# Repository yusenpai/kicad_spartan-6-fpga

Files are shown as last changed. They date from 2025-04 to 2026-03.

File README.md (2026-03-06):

# Spartan 6 FPGA Dev Board

Đây là thiết kế của một board FPGA dựa trên Xilinx Spartan-6 XC6SLX16, kiểu chân BGA 324 chân. Board tương thích với slot mini PCI Express. Trên board tích hợp 256MB DRAM DDR3, 1Gb NAND Flash và 32Mb NOR Flash phục vụ cho mục đích lưu trữ file cấu hình FPGA.
Board này phục vụ cho mục đích học tập, nghiên cứu liên quan tới FPGA.

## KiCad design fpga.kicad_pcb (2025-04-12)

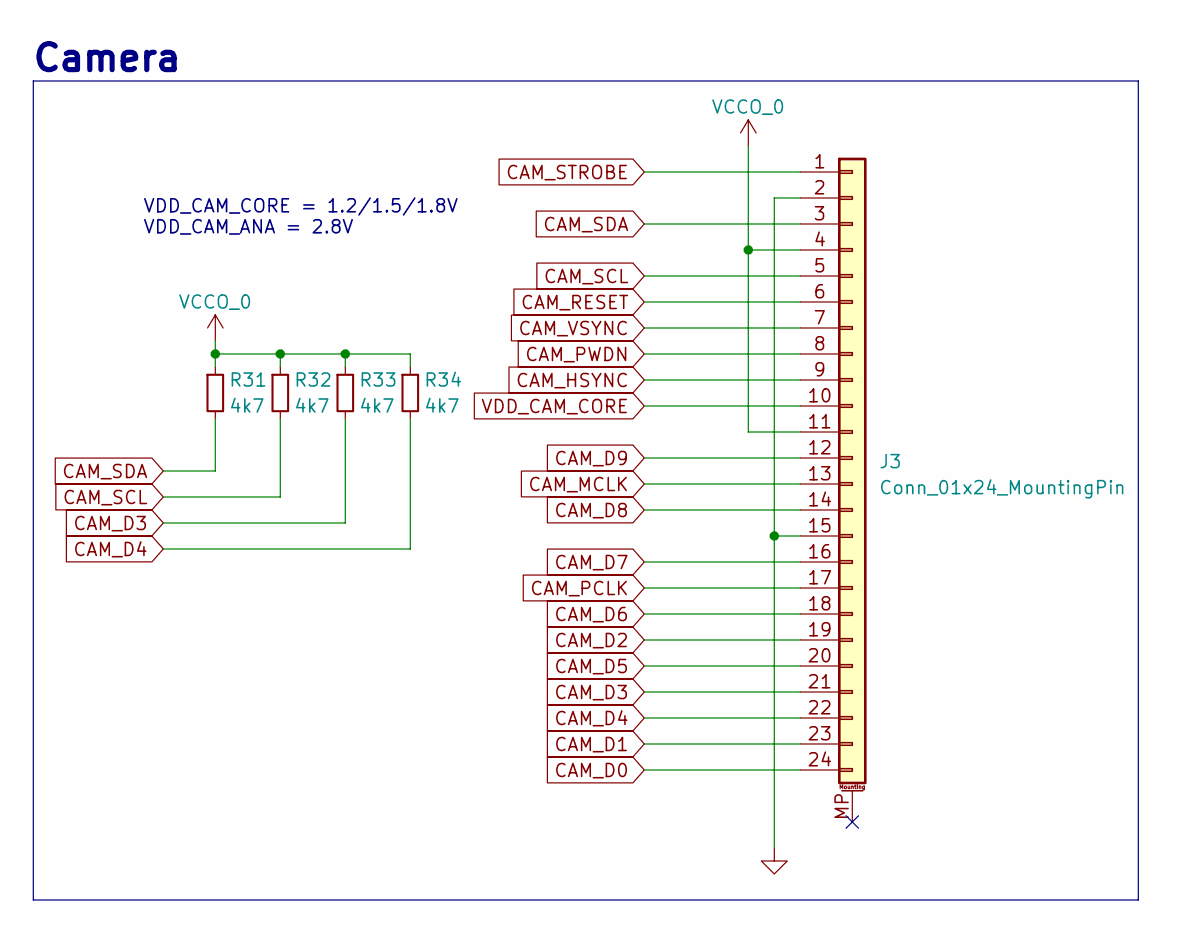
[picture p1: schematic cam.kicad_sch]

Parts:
J3: Conn_01x24_MountingPin; FPC-24P0.5
R31, R32, R33, R34: 4k7; R_0402_1005Metric

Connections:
+3V3: J3.4, J3.11, R31.1, R32.1, R33.1, R34.1; also elsewhere on the board
CAM_D0: J3.24; also elsewhere on the board
CAM_D1: J3.23; also elsewhere on the board
CAM_D2: J3.19; also elsewhere on the board
CAM_D3: J3.21, R33.2; also elsewhere on the board
CAM_D4: J3.22, R34.2; also elsewhere on the board
CAM_D5: J3.20; also elsewhere on the board
CAM_D6: J3.18; also elsewhere on the board
CAM_D7: J3.16; also elsewhere on the board
CAM_D8: J3.14; also elsewhere on the board
CAM_D9: J3.12; also elsewhere on the board
CAM_HSYNC: J3.9; also elsewhere on the board
CAM_MCLK: J3.13; also elsewhere on the board
CAM_PCLK: J3.17; also elsewhere on the board
CAM_PWDN: J3.8; also elsewhere on the board
CAM_RESET: J3.6; also elsewhere on the board
CAM_SCL: J3.5, R32.2; also elsewhere on the board
CAM_SDA: J3.3, R31.2; also elsewhere on the board
CAM_STROBE: J3.1; also elsewhere on the board
CAM_VSYNC: J3.7; also elsewhere on the board
GND: J3.2, J3.15; also elsewhere on the board
VDD_CAM_CORE: J3.10; also elsewhere on the board

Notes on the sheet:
Camera
VDD_CAM_CORE = 1.2/1.5/1.8V VDD_CAM_ANA = 2.8V

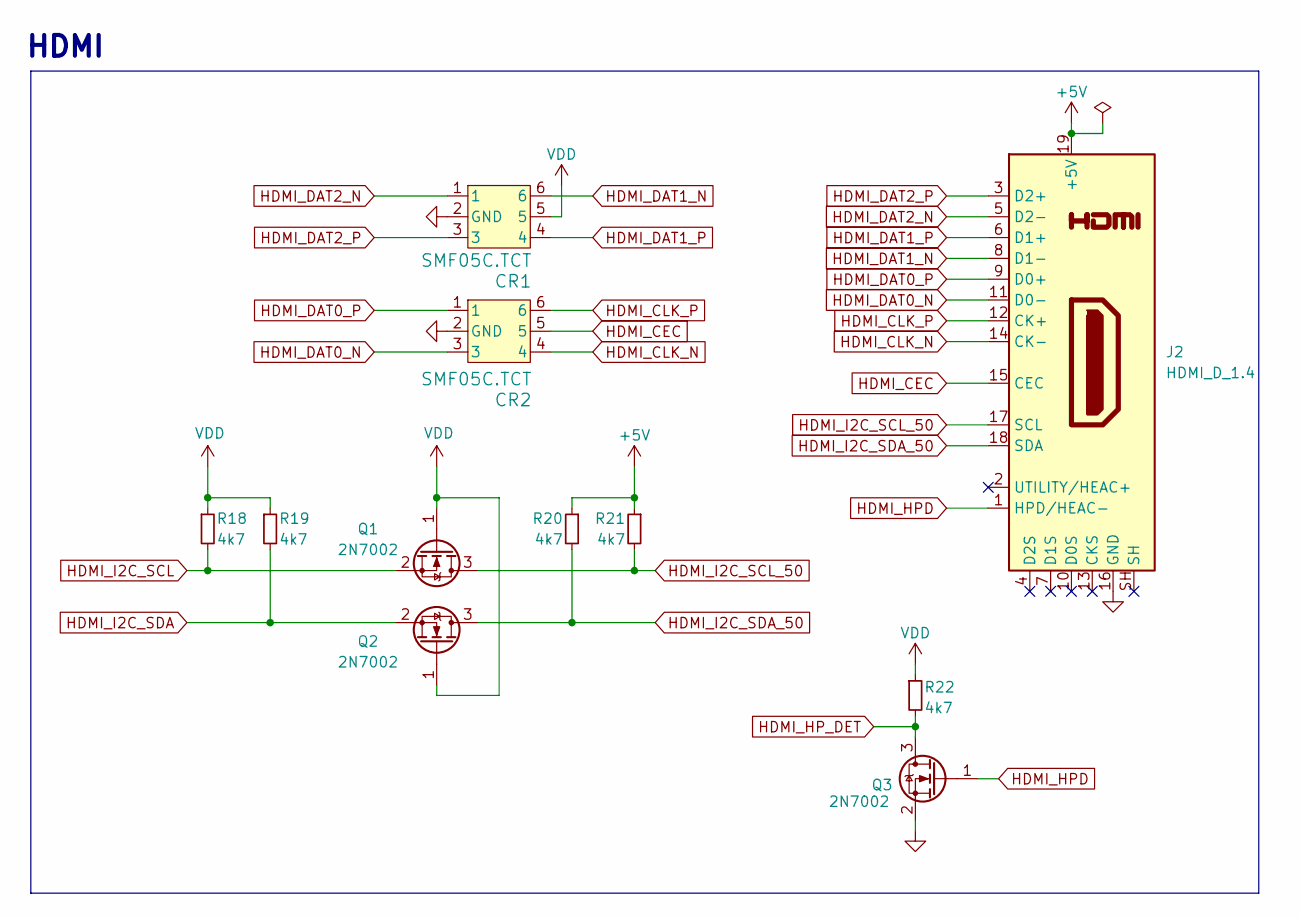
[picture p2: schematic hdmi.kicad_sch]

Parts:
CR1, CR2: SMF05C.TCT; TSOT-23-6
J2: HDMI_D_1.4; HDMI_Micro-D_Molex_46765-0x01
Q1, Q2, Q3: 2N7002; SOT-23
R18, R19, R20, R21, R22: 4k7; R_0402_1005Metric

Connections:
+3V3: CR1.5, Q1.1 (G), Q2.1 (G), R18.1, R19.1, R22.1; also elsewhere on the board
+5V: J2.19 (+5V), R20.1, R21.1; also elsewhere on the board
GND: CR1.2 (GND), CR2.2 (GND), J2.16 (GND), Q3.2 (S); also elsewhere on the board
HDMI_CEC: CR2.5, J2.15 (CEC); also elsewhere on the board
HDMI_CLK_N: CR2.4, J2.14 (CK-); also elsewhere on the board
HDMI_CLK_P: CR2.6, J2.12 (CK+); also elsewhere on the board
HDMI_DAT0_N: CR2.3, J2.11 (D0-); also elsewhere on the board
HDMI_DAT0_P: CR2.1, J2.9 (D0+); also elsewhere on the board
HDMI_DAT1_N: CR1.6, J2.8 (D1-); also elsewhere on the board
HDMI_DAT1_P: CR1.4, J2.6 (D1+); also elsewhere on the board
HDMI_DAT2_N: CR1.1, J2.5 (D2-); also elsewhere on the board
HDMI_DAT2_P: CR1.3, J2.3 (D2+); also elsewhere on the board
HDMI_HPD: J2.1 (HPD/HEAC-), Q3.1 (G)
HDMI_HP_DET: Q3.3 (D), R22.2; also elsewhere on the board
HDMI_I2C_SCL: Q1.2 (S), R18.2; also elsewhere on the board
HDMI_I2C_SCL_50: J2.17 (SCL), Q1.3 (D), R21.2
HDMI_I2C_SDA: Q2.2 (S), R19.2; also elsewhere on the board
HDMI_I2C_SDA_50: J2.18 (SDA), Q2.3 (D), R20.2

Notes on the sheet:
HDMI

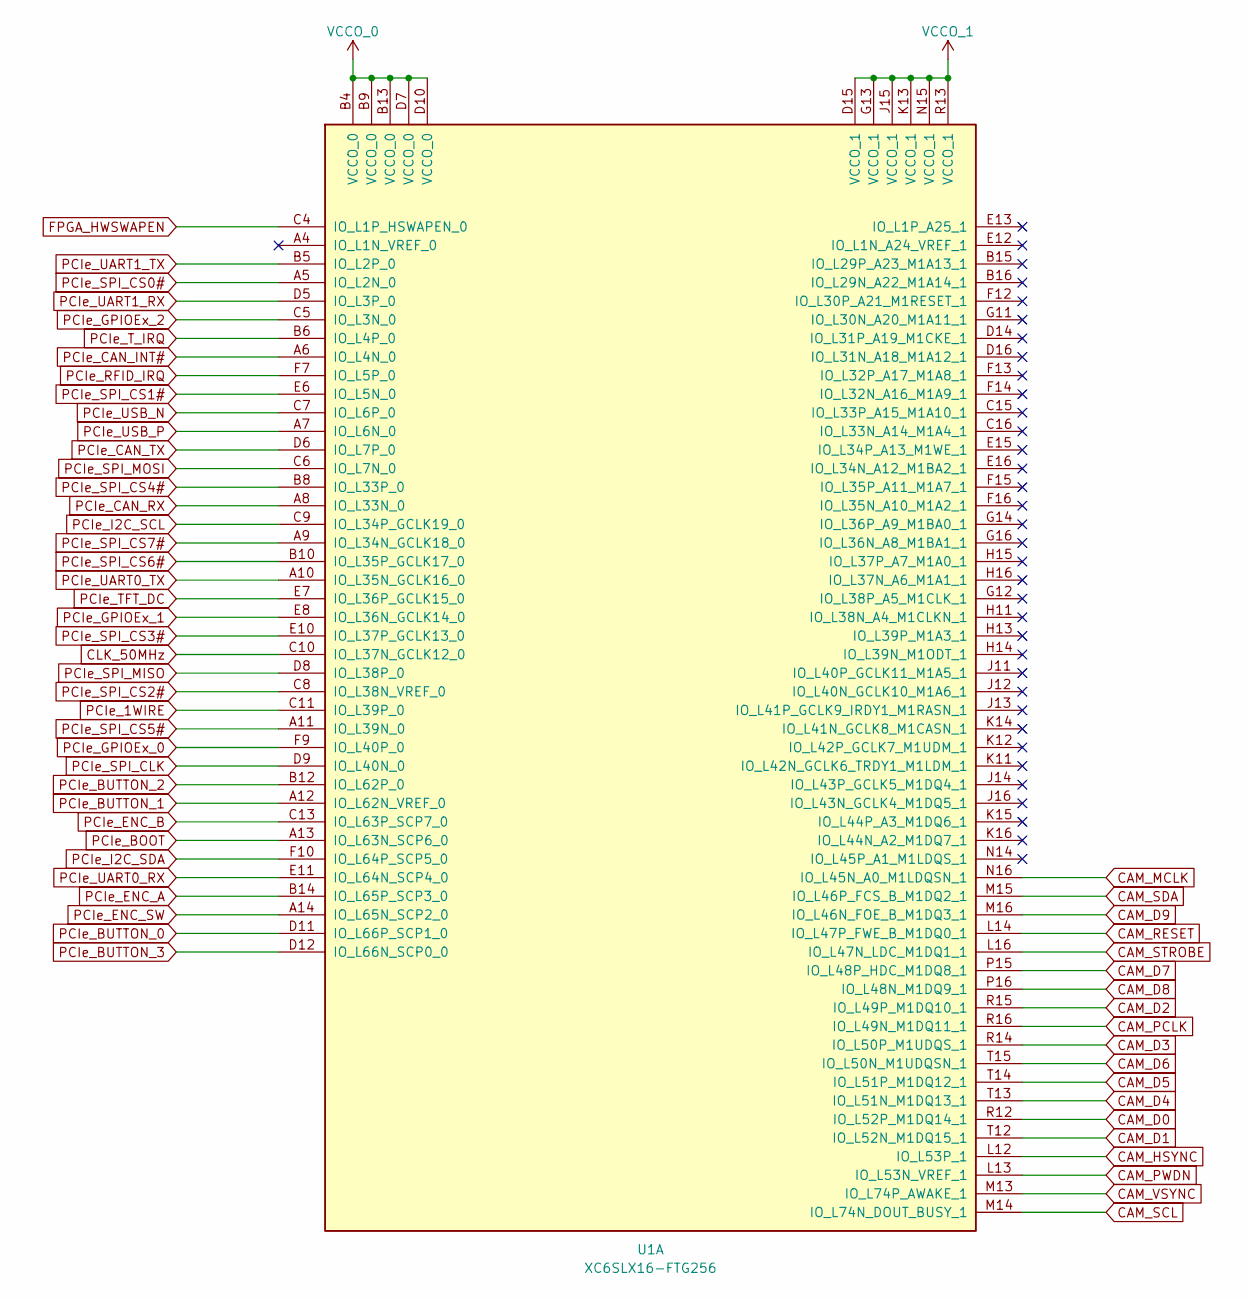
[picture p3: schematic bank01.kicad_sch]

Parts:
U1: XC6SLX16-FTG256; BGA-256_17.0x17.0mm_Layout16x16_P1.0mm_Ball0.5mm_Pad0.4mm_N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

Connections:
+2V8: U1.D15 (VCCO_1), U1.G13 (VCCO_1), U1.J15 (VCCO_1), U1.K13 (VCCO_1), U1.N15 (VCCO_1), U1.R13 (VCCO_1); also elsewhere on the board
+3V3: U1.B4 (VCCO_0), U1.B9 (VCCO_0), U1.B13 (VCCO_0), U1.D7 (VCCO_0), U1.D10 (VCCO_0); also elsewhere on the board
CAM_D0: U1.R12 (IO_L52P_M1DQ14_1); also elsewhere on the board
CAM_D1: U1.T12 (IO_L52N_M1DQ15_1); also elsewhere on the board
CAM_D2: U1.R15 (IO_L49P_M1DQ10_1); also elsewhere on the board
CAM_D3: U1.R14 (IO_L50P_M1UDQS_1); also elsewhere on the board
CAM_D4: U1.T13 (IO_L51N_M1DQ13_1); also elsewhere on the board
CAM_D5: U1.T14 (IO_L51P_M1DQ12_1); also elsewhere on the board
CAM_D6: U1.T15 (IO_L50N_M1UDQSN_1); also elsewhere on the board
CAM_D7: U1.P15 (IO_L48P_HDC_M1DQ8_1); also elsewhere on the board
CAM_D8: U1.P16 (IO_L48N_M1DQ9_1); also elsewhere on the board
CAM_D9: U1.M16 (IO_L46N_FOE_B_M1DQ3_1); also elsewhere on the board
CAM_HSYNC: U1.L12 (IO_L53P_1); also elsewhere on the board
CAM_MCLK: U1.N16 (IO_L45N_A0_M1LDQSN_1); also elsewhere on the board
CAM_PCLK: U1.R16 (IO_L49N_M1DQ11_1); also elsewhere on the board
CAM_PWDN: U1.L13 (IO_L53N_VREF_1); also elsewhere on the board
CAM_RESET: U1.L14 (IO_L47P_FWE_B_M1DQ0_1); also elsewhere on the board
CAM_SCL: U1.M14 (IO_L74N_DOUT_BUSY_1); also elsewhere on the board
CAM_SDA: U1.M15 (IO_L46P_FCS_B_M1DQ2_1); also elsewhere on the board
CAM_STROBE: U1.L16 (IO_L47N_LDC_M1DQ1_1); also elsewhere on the board
CAM_VSYNC: U1.M13 (IO_L74P_AWAKE_1); also elsewhere on the board
CLK_50MHz: U1.C10 (IO_L37N_GCLK12_0); also elsewhere on the board
FPGA_HWSWAPEN: U1.C4 (IO_L1P_HSWAPEN_0); also elsewhere on the board
PCIe_1WIRE: U1.C11 (IO_L39P_0); also elsewhere on the board
PCIe_BOOT: U1.A13 (IO_L63N_SCP6_0); also elsewhere on the board
PCIe_BUTTON_0: U1.D11 (IO_L66P_SCP1_0); also elsewhere on the board
PCIe_BUTTON_1: U1.A12 (IO_L62N_VREF_0); also elsewhere on the board
PCIe_BUTTON_2: U1.B12 (IO_L62P_0); also elsewhere on the board
PCIe_BUTTON_3: U1.D12 (IO_L66N_SCP0_0); also elsewhere on the board
PCIe_CAN_INT#: U1.A6 (IO_L4N_0); also elsewhere on the board
PCIe_CAN_RX: U1.A8 (IO_L33N_0); also elsewhere on the board
PCIe_CAN_TX: U1.D6 (IO_L7P_0); also elsewhere on the board
PCIe_ENC_A: U1.B14 (IO_L65P_SCP3_0); also elsewhere on the board
PCIe_ENC_B: U1.C13 (IO_L63P_SCP7_0); also elsewhere on the board
PCIe_ENC_SW: U1.A14 (IO_L65N_SCP2_0); also elsewhere on the board
PCIe_GPIOEx_0: U1.F9 (IO_L40P_0); also elsewhere on the board
PCIe_GPIOEx_1: U1.E8 (IO_L36N_GCLK14_0); also elsewhere on the board
PCIe_GPIOEx_2: U1.C5 (IO_L3N_0); also elsewhere on the board
PCIe_I2C_SCL: U1.C9 (IO_L34P_GCLK19_0); also elsewhere on the board
PCIe_I2C_SDA: U1.F10 (IO_L64P_SCP5_0); also elsewhere on the board
PCIe_RFID_IRQ: U1.F7 (IO_L5P_0); also elsewhere on the board
PCIe_SPI_CLK: U1.D9 (IO_L40N_0); also elsewhere on the board
PCIe_SPI_CS0#: U1.A5 (IO_L2N_0); also elsewhere on the board
PCIe_SPI_CS1#: U1.E6 (IO_L5N_0); also elsewhere on the board
PCIe_SPI_CS2#: U1.C8 (IO_L38N_VREF_0); also elsewhere on the board
PCIe_SPI_CS3#: U1.E10 (IO_L37P_GCLK13_0); also elsewhere on the board
PCIe_SPI_CS4#: U1.B8 (IO_L33P_0); also elsewhere on the board
PCIe_SPI_CS5#: U1.A11 (IO_L39N_0); also elsewhere on the board
PCIe_SPI_CS6#: U1.B10 (IO_L35P_GCLK17_0); also elsewhere on the board
PCIe_SPI_CS7#: U1.A9 (IO_L34N_GCLK18_0); also elsewhere on the board
PCIe_SPI_MISO: U1.D8 (IO_L38P_0); also elsewhere on the board
PCIe_SPI_MOSI: U1.C6 (IO_L7N_0); also elsewhere on the board
PCIe_TFT_DC: U1.E7 (IO_L36P_GCLK15_0); also elsewhere on the board
PCIe_T_IRQ: U1.B6 (IO_L4P_0); also elsewhere on the board
PCIe_UART0_RX: U1.E11 (IO_L64N_SCP4_0); also elsewhere on the board
PCIe_UART0_TX: U1.A10 (IO_L35N_GCLK16_0); also elsewhere on the board
PCIe_UART1_RX: U1.D5 (IO_L3P_0); also elsewhere on the board
PCIe_UART1_TX: U1.B5 (IO_L2P_0); also elsewhere on the board
PCIe_USB_N: U1.C7 (IO_L6P_0); also elsewhere on the board
PCIe_USB_P: U1.A7 (IO_L6N_0); also elsewhere on the board

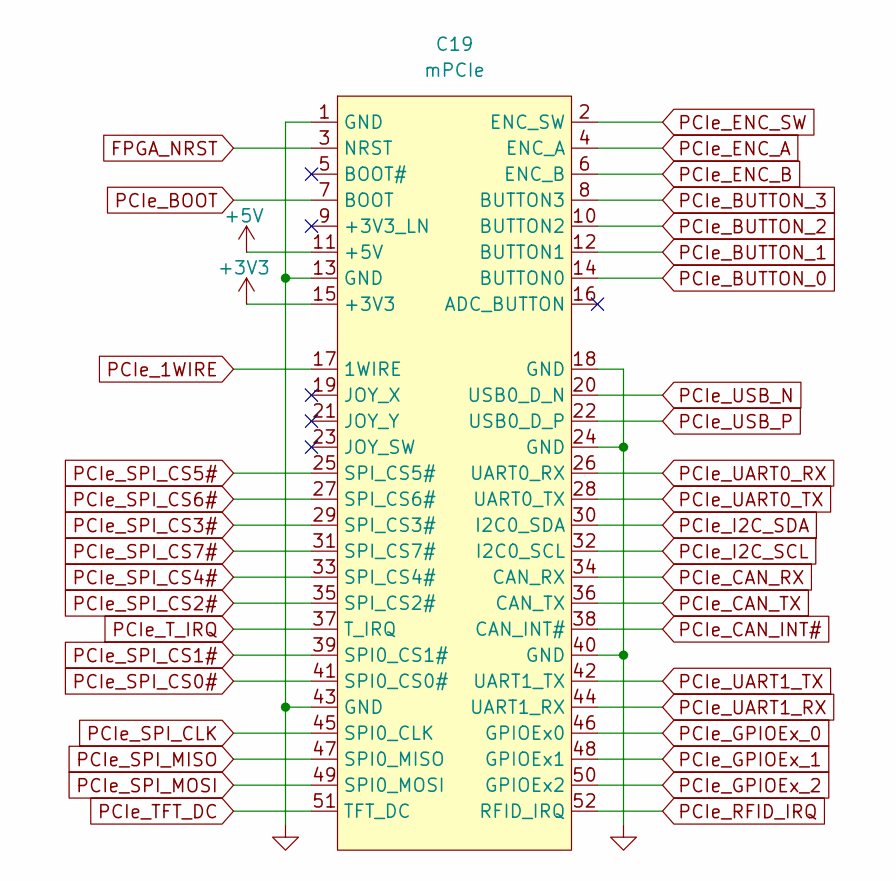
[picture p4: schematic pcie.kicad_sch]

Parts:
C19: mPCIe; mpcie-full-card

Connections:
+3V3: C19.15 (+3V3); also elsewhere on the board
+5V: C19.11 (+5V); also elsewhere on the board
FPGA_NRST: C19.3 (NRST); also elsewhere on the board
GND: C19.1 (GND), C19.13 (GND), C19.18 (GND), C19.24 (GND), C19.40 (GND), C19.43 (GND); also elsewhere on the board
PCIe_1WIRE: C19.17 (1WIRE); also elsewhere on the board
PCIe_BOOT: C19.7 (BOOT); also elsewhere on the board
PCIe_BUTTON_0: C19.14 (BUTTON0); also elsewhere on the board
PCIe_BUTTON_1: C19.12 (BUTTON1); also elsewhere on the board
PCIe_BUTTON_2: C19.10 (BUTTON2); also elsewhere on the board
PCIe_BUTTON_3: C19.8 (BUTTON3); also elsewhere on the board
PCIe_CAN_INT#: C19.38 (CAN_INT#); also elsewhere on the board
PCIe_CAN_RX: C19.34 (CAN_RX); also elsewhere on the board
PCIe_CAN_TX: C19.36 (CAN_TX); also elsewhere on the board
PCIe_ENC_A: C19.4 (ENC_A); also elsewhere on the board
PCIe_ENC_B: C19.6 (ENC_B); also elsewhere on the board
PCIe_ENC_SW: C19.2 (ENC_SW); also elsewhere on the board
PCIe_GPIOEx_0: C19.46 (GPIOEx0); also elsewhere on the board
PCIe_GPIOEx_1: C19.48 (GPIOEx1); also elsewhere on the board
PCIe_GPIOEx_2: C19.50 (GPIOEx2); also elsewhere on the board
PCIe_I2C_SCL: C19.32 (I2C0_SCL); also elsewhere on the board
PCIe_I2C_SDA: C19.30 (I2C0_SDA); also elsewhere on the board
PCIe_RFID_IRQ: C19.52 (RFID_IRQ); also elsewhere on the board
PCIe_SPI_CLK: C19.45 (SPI0_CLK); also elsewhere on the board
PCIe_SPI_CS0#: C19.41 (SPI0_CS0#); also elsewhere on the board
PCIe_SPI_CS1#: C19.39 (SPI0_CS1#); also elsewhere on the board
PCIe_SPI_CS2#: C19.35 (SPI_CS2#); also elsewhere on the board
PCIe_SPI_CS3#: C19.29 (SPI_CS3#); also elsewhere on the board
PCIe_SPI_CS4#: C19.33 (SPI_CS4#); also elsewhere on the board
PCIe_SPI_CS5#: C19.25 (SPI_CS5#); also elsewhere on the board
PCIe_SPI_CS6#: C19.27 (SPI_CS6#); also elsewhere on the board
PCIe_SPI_CS7#: C19.31 (SPI_CS7#); also elsewhere on the board
PCIe_SPI_MISO: C19.47 (SPI0_MISO); also elsewhere on the board
PCIe_SPI_MOSI: C19.49 (SPI0_MOSI); also elsewhere on the board
PCIe_TFT_DC: C19.51 (TFT_DC); also elsewhere on the board
PCIe_T_IRQ: C19.37 (T_IRQ); also elsewhere on the board
PCIe_UART0_RX: C19.26 (UART0_RX); also elsewhere on the board
PCIe_UART0_TX: C19.28 (UART0_TX); also elsewhere on the board
PCIe_UART1_RX: C19.44 (UART1_RX); also elsewhere on the board
PCIe_UART1_TX: C19.42 (UART1_TX); also elsewhere on the board
PCIe_USB_N: C19.20 (USB0_D_N); also elsewhere on the board
PCIe_USB_P: C19.22 (USB0_D_P); also elsewhere on the board

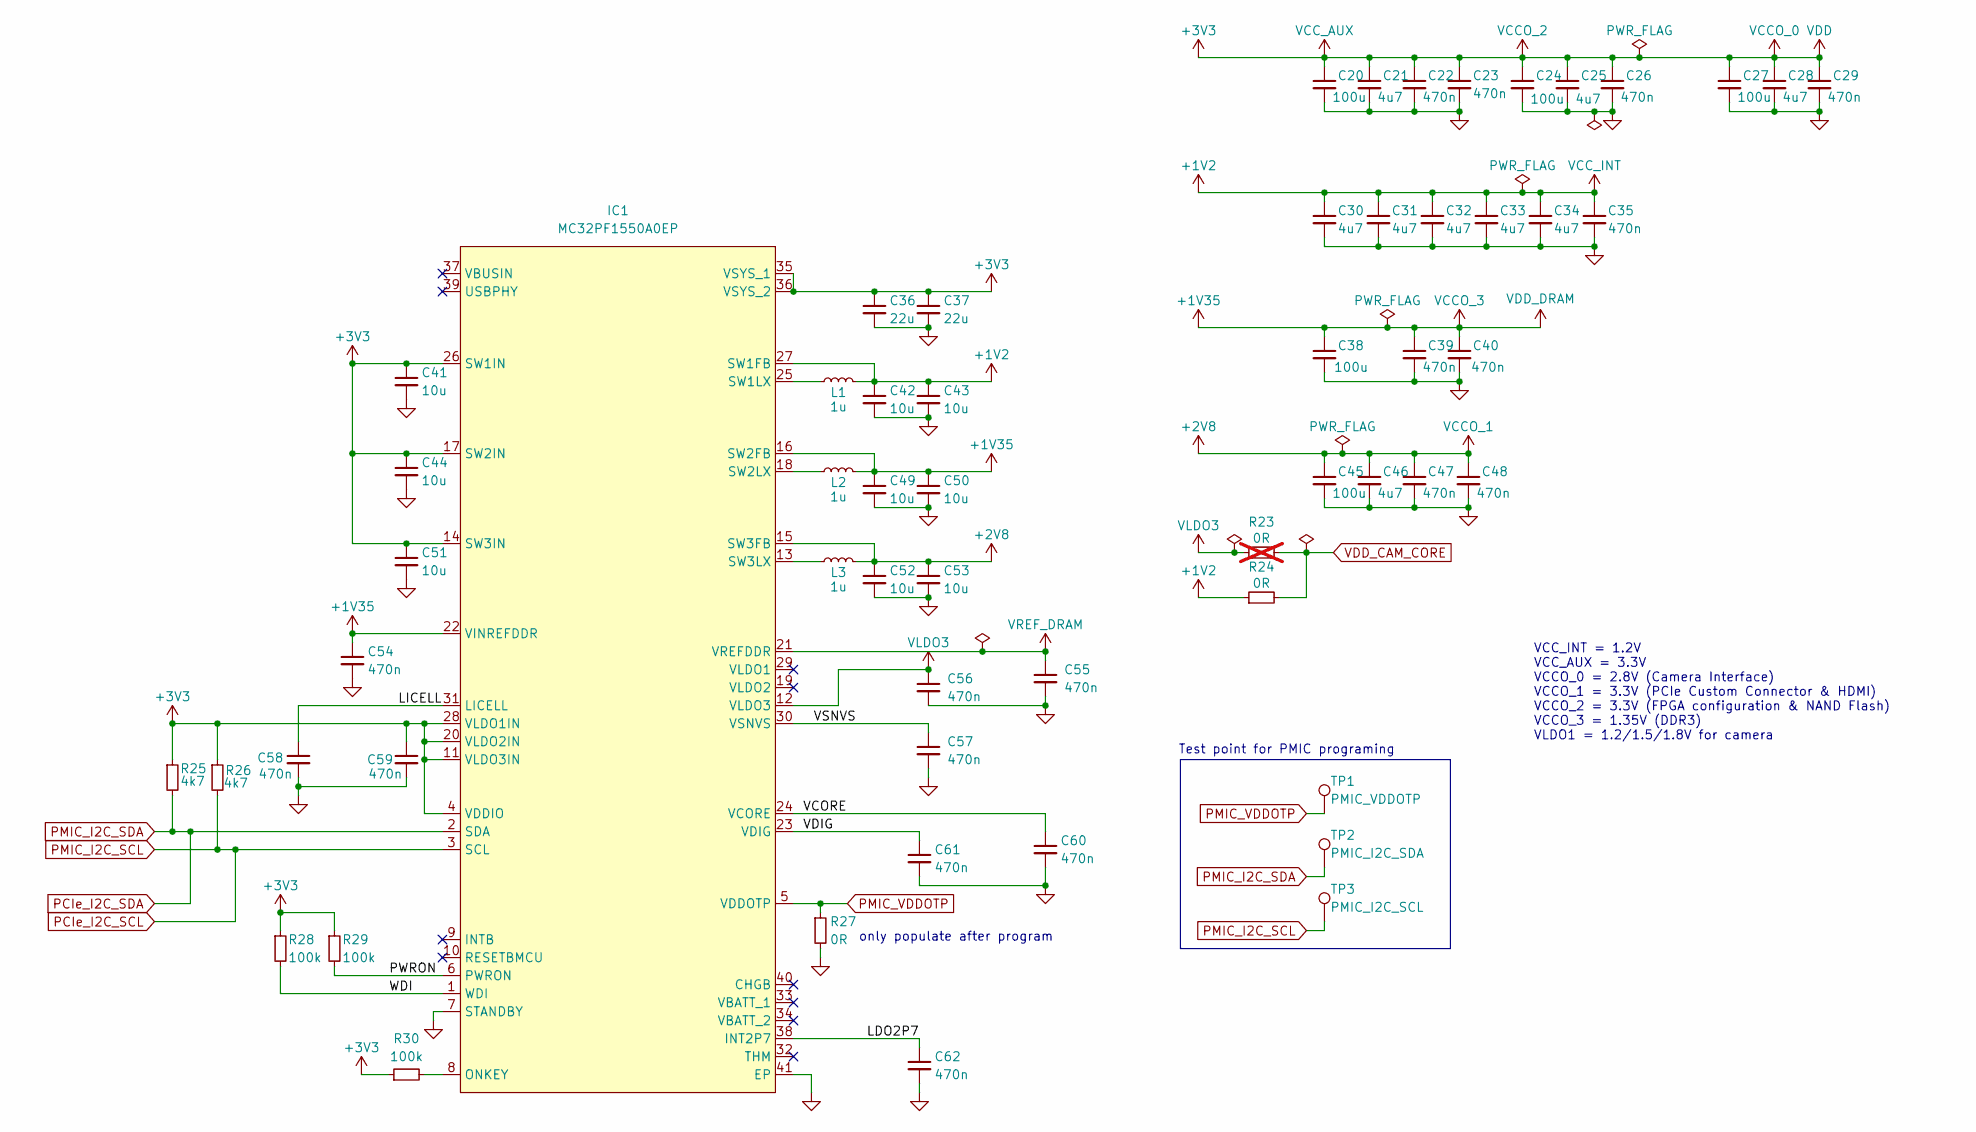
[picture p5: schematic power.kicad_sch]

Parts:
C20, C24, C27, C38, C45: 100u; C_1206_3216Metric
C21, C25, C28, C30, C31, C32, C33, C34, C46: 4u7; C_0603_1608Metric
C22, C23, C26, C29, C35, C39, C40, C47, C48, C54, C55, C56, C57, C58, C59, C60, C61, C62: 470n; C_0402_1005Metric
C36, C37: 22u; C_0603_1608Metric
C41, C42, C43, C44, C49, C50, C51, C52, C53: 10u; C_0603_1608Metric
IC1: MC32PF1550A0EP; QFN-40-1EP_5x5mm_P0.4mm_EP3.8x3.8mm; Manufacturer_Part_Number MC32PF1550A0EP; Mouser Part Number 771-MC32PF1550A0EP
L1, L2, L3: 1u; L_Wurth_WE-LQSH-4020
R23: 0R; R_0402_1005Metric; not fitted
R24, R27: 0R; R_0402_1005Metric
R25, R26: 4k7; R_0402_1005Metric
R28, R29, R30: 100k; R_0402_1005Metric
TP1: PMIC_VDDOTP; TestPoint_Pad_D1.0mm
TP2: PMIC_I2C_SDA; TestPoint_Pad_D1.0mm
TP3: PMIC_I2C_SCL; TestPoint_Pad_D1.0mm

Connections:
+1V2: C30.1, C31.1, C32.1, C33.1, C34.1, C35.1, C42.1, C43.1, IC1.27 (SW1FB), L1.2, R24.1; also elsewhere on the board
+1V35: C38.1, C39.1, C40.1, C49.1, C50.1, C54.1, IC1.16 (SW2FB), IC1.22 (VINREFDDR), L2.2; also elsewhere on the board
+2V8: C45.1, C46.1, C47.1, C48.1, C52.1, C53.1, IC1.15 (SW3FB), L3.2; also elsewhere on the board
+3V3: C20.1, C21.1, C22.1, C23.1, C24.1, C25.1, C26.1, C27.1, C28.1, C29.1, C36.1, C37.1, C41.1, C44.1, C51.1, C59.1, IC1.4 (VDDIO), IC1.11 (VLDO3IN), IC1.14 (SW3IN), IC1.17 (SW2IN), IC1.20 (VLDO2IN), IC1.26 (SW1IN), IC1.28 (VLDO1IN), IC1.35 (VSYS_1), IC1.36 (VSYS_2), R25.1, R26.1, R28.1, R29.1, R30.1; also elsewhere on the board
/Power/LDO2P7: C62.1, IC1.38 (INT2P7)
/Power/LICELL: C58.1, IC1.31 (LICELL)
/Power/PWRON: IC1.6 (PWRON), R29.2
/Power/VCORE: C60.1, IC1.24 (VCORE)
/Power/VDIG: C61.1, IC1.23 (VDIG)
/Power/VSNVS: C57.1, IC1.30 (VSNVS)
/Power/WDI: IC1.1 (WDI), R28.2
GND: C20.2, C21.2, C22.2, C23.2, C24.2, C25.2, C26.2, C27.2, C28.2, C29.2, C30.2, C31.2, C32.2, C33.2, C34.2, C35.2, C36.2, C37.2, C38.2, C39.2, C40.2, C41.2, C42.2, C43.2, C44.2, C45.2, C46.2, C47.2, C48.2, C49.2, C50.2, C51.2, C52.2, C53.2, C54.2, C55.2, C56.2, C57.2, C58.2, C59.2, C60.2, C61.2, C62.2, IC1.7 (STANDBY), IC1.41 (EP), R27.2; also elsewhere on the board
unnamed: IC1.8 (ONKEY), R30.2
unnamed: IC1.25 (SW1LX), L1.1
unnamed: IC1.18 (SW2LX), L2.1
unnamed: IC1.13 (SW3LX), L3.1
PCIe_I2C_SCL: IC1.3 (SCL), R26.2, TP3.1; also elsewhere on the board
PCIe_I2C_SDA: IC1.2 (SDA), R25.2, TP2.1; also elsewhere on the board
PMIC_VDDOTP: IC1.5 (VDDOTP), R27.1, TP1.1
VDD_CAM_CORE: R23.2, R24.2; also elsewhere on the board
VLDO3: C56.1, IC1.12 (VLDO3), R23.1
VREF_DRAM: C55.1, IC1.21 (VREFDDR); also elsewhere on the board

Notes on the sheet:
only populate after program
VCC_INT = 1.2V VCC_AUX = 3.3V VCCO_0 = 2.8V (Camera Interface) VCCO_1 = 3.3V (PCIe Custom Connector & HDMI) VCCO_2 = 3.3V (FPGA configuration & NAND Flash) VCCO_3 = 1.35V (DDR3) VLDO1 = 1.2/1.5/1.8V for camera
Test point for PMIC programing

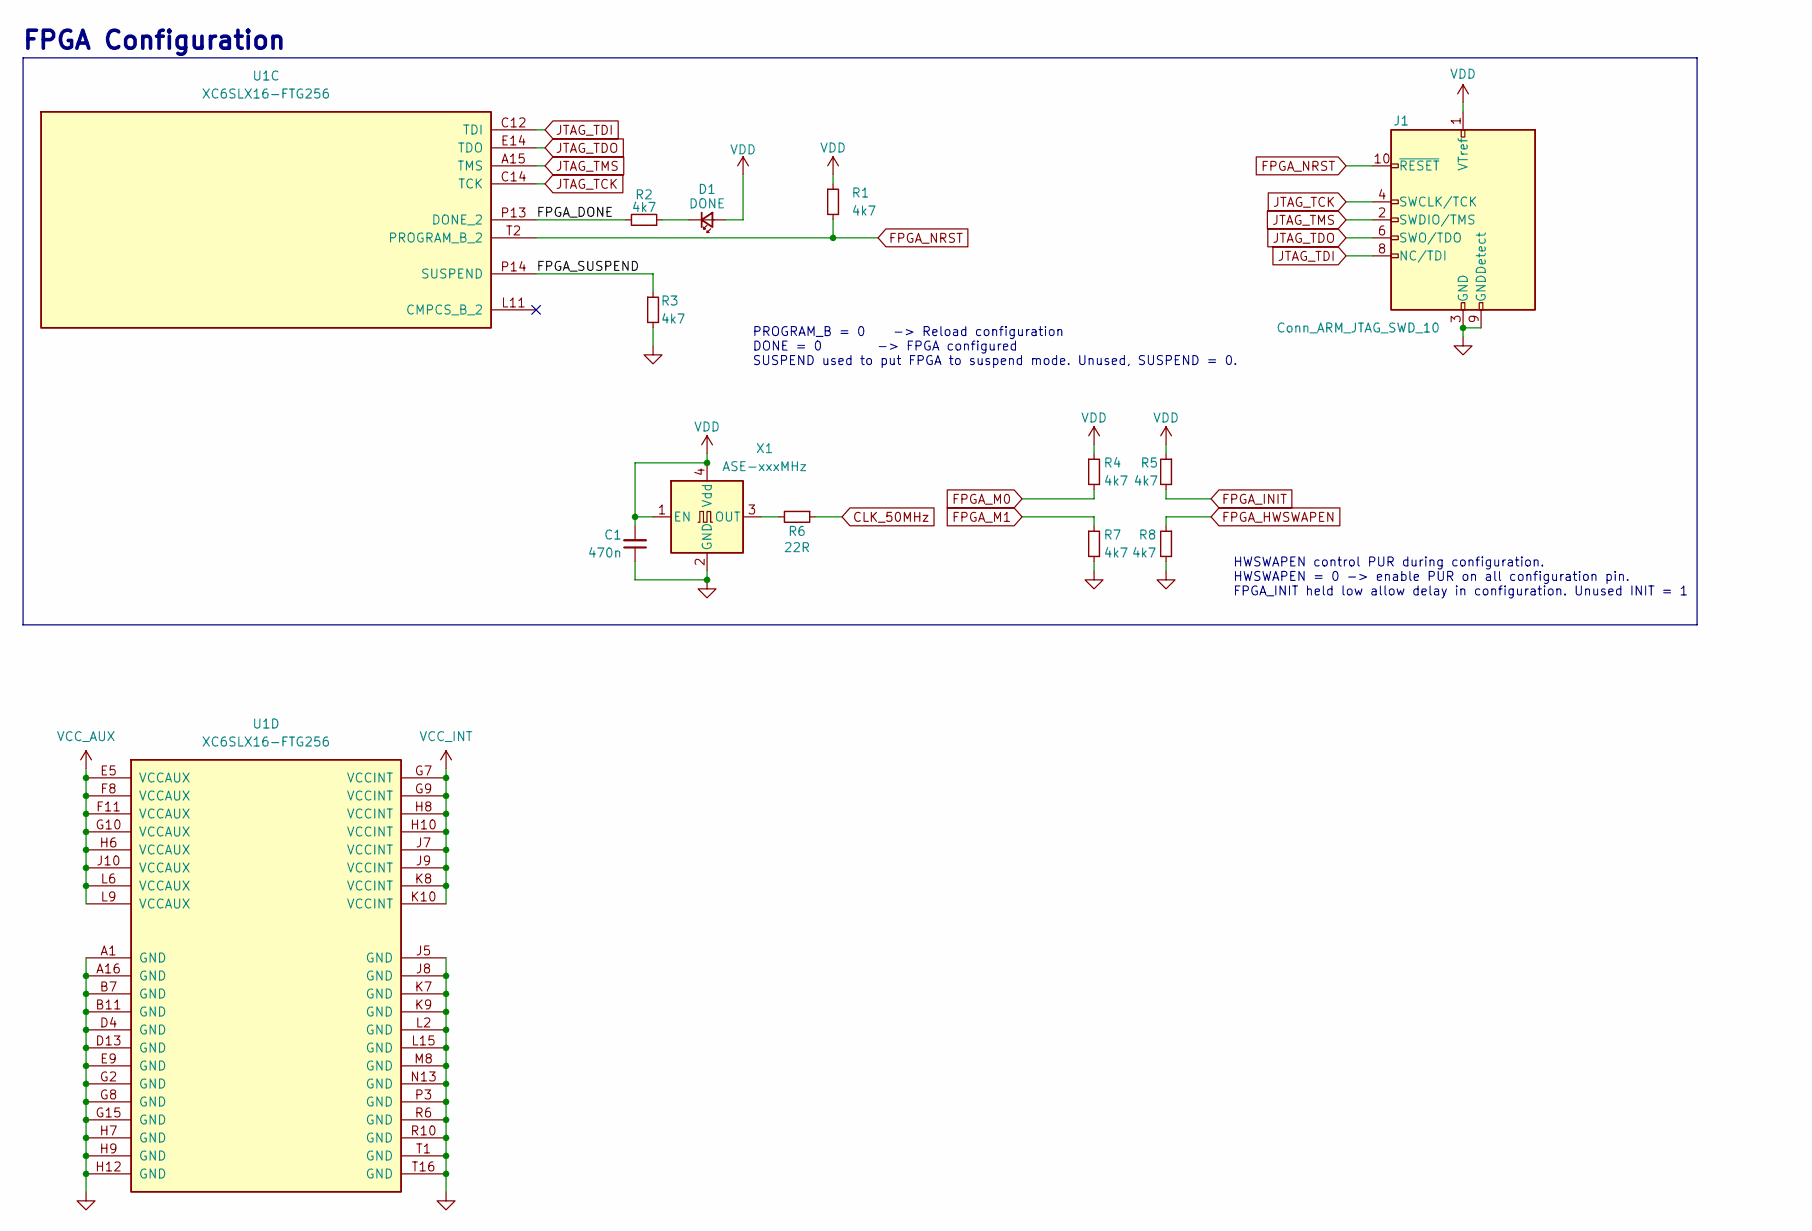
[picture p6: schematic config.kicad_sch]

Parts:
C1: 470n; C_0402_1005Metric
D1: DONE; LED_0603_1608Metric
J1: Conn_ARM_JTAG_SWD_10; PinHeader_2x05_P1.27mm_Vertical_SMD
R1, R2, R3, R4, R5, R7, R8: 4k7; R_0402_1005Metric
R6: 22R; R_0402_1005Metric
U1: XC6SLX16-FTG256; BGA-256_17.0x17.0mm_Layout16x16_P1.0mm_Ball0.5mm_Pad0.4mm_N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
X1: ASE-xxxMHz; Oscillator_SMD_Abracon_ASE-4Pin_3.2x2.5mm

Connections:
+1V2: U1.G7 (VCCINT), U1.G9 (VCCINT), U1.H8 (VCCINT), U1.H10 (VCCINT), U1.J7 (VCCINT), U1.J9 (VCCINT), U1.K8 (VCCINT), U1.K10 (VCCINT); also elsewhere on the board
+3V3: C1.2, D1.2 (A), J1.1 (VTref), R1.1, R4.1, R5.1, U1.E5 (VCCAUX), U1.F8 (VCCAUX), U1.F11 (VCCAUX), U1.G10 (VCCAUX), U1.H6 (VCCAUX), U1.J10 (VCCAUX), U1.L6 (VCCAUX), U1.L9 (VCCAUX), X1.1 (EN), X1.4 (Vdd); also elsewhere on the board
/FPGA Configuration/FPGA_DONE: R2.2, U1.P13 (DONE_2)
/FPGA Configuration/FPGA_SUSPEND: R3.1, U1.P14 (SUSPEND)
CLK_50MHz: R6.1; also elsewhere on the board
FPGA_HWSWAPEN: R8.1; also elsewhere on the board
FPGA_INIT: R5.2; also elsewhere on the board
FPGA_M0: R4.2; also elsewhere on the board
FPGA_M1: R7.1; also elsewhere on the board
FPGA_NRST: J1.10 (~RESET), R1.2, U1.T2 (PROGRAM_B_2); also elsewhere on the board
GND: C1.1, J1.3 (GND), J1.5 (GND), J1.9 (GNDDetect), R3.2, R7.2, R8.2, U1.A1 (GND), U1.A16 (GND), U1.B7 (GND), U1.B11 (GND), U1.D4 (GND), U1.D13 (GND), U1.E9 (GND), U1.G2 (GND), U1.G8 (GND), U1.G15 (GND), U1.H7 (GND), U1.H9 (GND), U1.H12 (GND), U1.J5 (GND), U1.J8 (GND), U1.K7 (GND), U1.K9 (GND), U1.L2 (GND), U1.L15 (GND), U1.M8 (GND), U1.N13 (GND), U1.P3 (GND), U1.R6 (GND), U1.R10 (GND), U1.T1 (GND), U1.T16 (GND), X1.2 (GND); also elsewhere on the board
JTAG_TCK: J1.4 (SWCLK/TCK), U1.C14 (TCK)
JTAG_TDI: J1.8 (NC/TDI), U1.C12 (TDI)
JTAG_TDO: J1.6 (SWO/TDO), U1.E14 (TDO)
JTAG_TMS: J1.2 (SWDIO/TMS), U1.A15 (TMS)
unnamed: D1.1 (K), R2.1
unnamed: R6.2, X1.3 (OUT)

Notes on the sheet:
FPGA Configuration
PROGRAM_B = 0 -> Reload configuration DONE = 0 -> FPGA configured SUSPEND used to put FPGA to suspend mode. Unused, SUSPEND = 0.
HWSWAPEN control PUR during configuration. HWSWAPEN = 0 -> enable PUR on all configuration pin. FPGA_INIT held low allow delay in configuration. Unused INIT = 1

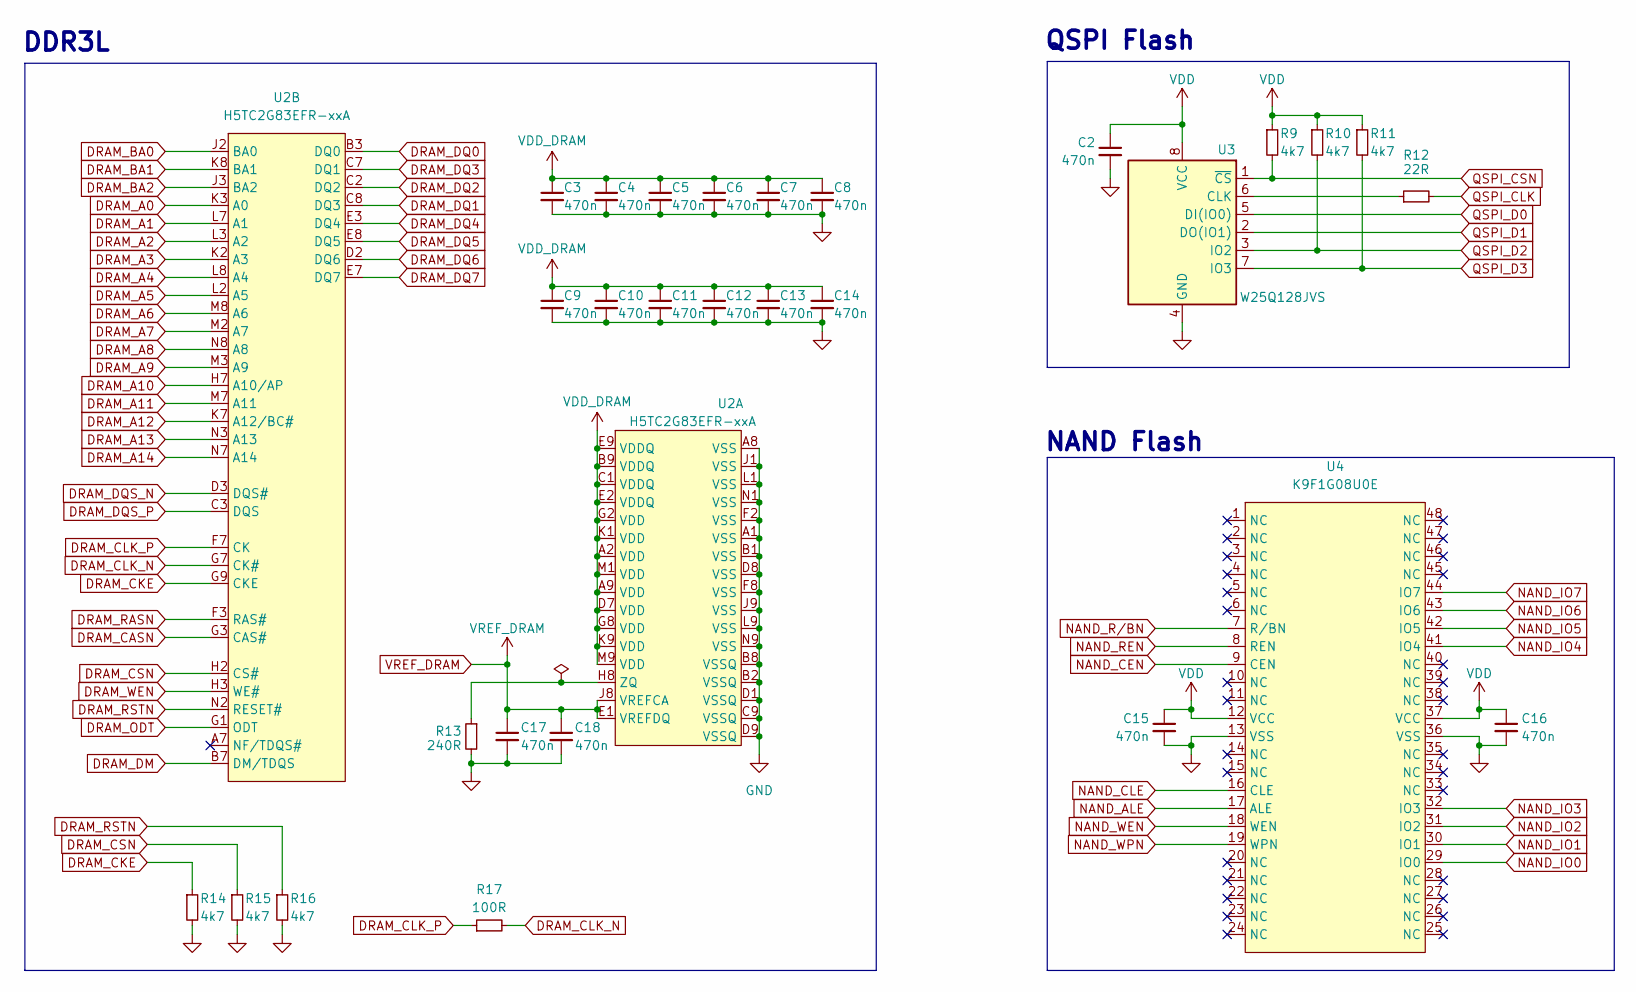
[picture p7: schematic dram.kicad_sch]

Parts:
C2, C3, C4, C5, C6, C7, C8, C9, C10, C11, C12, C13, C14, C15, C16, C17, C18: 470n; C_0402_1005Metric
R9, R10, R11, R14, R15, R16: 4k7; R_0402_1005Metric
R12: 22R; R_0402_1005Metric
R13: 240R; R_0402_1005Metric
R17: 100R; R_0402_1005Metric
U2: H5TC2G83EFR-xxA; FBGA-78_7.5x11mm_Layout2x3x13_P0.8mm
U3: W25Q128JVS; SOIC-8_5.23x5.23mm_P1.27mm
U4: K9F1G08U0E; TSOP-I-48_18.4x12mm_P0.5mm

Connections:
+1V35: C3.1, C4.1, C5.1, C6.1, C7.1, C8.1, C9.1, C10.1, C11.1, C12.1, C13.1, C14.1, U2.A2 (VDD), U2.A9 (VDD), U2.B9 (VDDQ), U2.C1 (VDDQ), U2.D7 (VDD), U2.E2 (VDDQ), U2.E9 (VDDQ), U2.G2 (VDD), U2.G8 (VDD), U2.K1 (VDD), U2.K9 (VDD), U2.M1 (VDD), U2.M9 (VDD); also elsewhere on the board
+3V3: C2.1, C15.1, C16.1, R9.1, R10.1, R11.1, U3.8 (VCC), U4.12 (VCC), U4.37 (VCC); also elsewhere on the board
DRAM_A0: U2.K3 (A0); also elsewhere on the board
DRAM_A1: U2.L7 (A1); also elsewhere on the board
DRAM_A2: U2.L3 (A2); also elsewhere on the board
DRAM_A3: U2.K2 (A3); also elsewhere on the board
DRAM_A4: U2.L8 (A4); also elsewhere on the board
DRAM_A5: U2.L2 (A5); also elsewhere on the board
DRAM_A6: U2.M8 (A6); also elsewhere on the board
DRAM_A7: U2.M2 (A7); also elsewhere on the board
DRAM_A8: U2.N8 (A8); also elsewhere on the board
DRAM_A9: U2.M3 (A9); also elsewhere on the board
DRAM_A10: U2.H7 (A10/AP); also elsewhere on the board
DRAM_A11: U2.M7 (A11); also elsewhere on the board
DRAM_A12: U2.K7 (A12/BC#); also elsewhere on the board
DRAM_A13: U2.N3 (A13); also elsewhere on the board
DRAM_A14: U2.N7 (A14); also elsewhere on the board
DRAM_BA0: U2.J2 (BA0); also elsewhere on the board
DRAM_BA1: U2.K8 (BA1); also elsewhere on the board
DRAM_BA2: U2.J3 (BA2); also elsewhere on the board
DRAM_CASN: U2.G3 (CAS#); also elsewhere on the board
DRAM_CKE: R14.1, U2.G9 (CKE); also elsewhere on the board
DRAM_CLK_N: R17.2, U2.G7 (CK#); also elsewhere on the board
DRAM_CLK_P: R17.1, U2.F7 (CK); also elsewhere on the board
DRAM_CSN: R15.1, U2.H2 (CS#)
DRAM_DM: U2.B7 (DM/TDQS); also elsewhere on the board
DRAM_DQ0: U2.B3 (DQ0); also elsewhere on the board
DRAM_DQ1: U2.C8 (DQ3); also elsewhere on the board
DRAM_DQ2: U2.C2 (DQ2); also elsewhere on the board
DRAM_DQ3: U2.C7 (DQ1); also elsewhere on the board
DRAM_DQ4: U2.E3 (DQ4); also elsewhere on the board
DRAM_DQ5: U2.E8 (DQ5); also elsewhere on the board
DRAM_DQ6: U2.D2 (DQ6); also elsewhere on the board
DRAM_DQ7: U2.E7 (DQ7); also elsewhere on the board
DRAM_DQS_N: U2.D3 (DQS#); also elsewhere on the board
DRAM_DQS_P: U2.C3 (DQS); also elsewhere on the board
DRAM_ODT: U2.G1 (ODT); also elsewhere on the board
DRAM_RASN: U2.F3 (RAS#); also elsewhere on the board
DRAM_RSTN: R16.1, U2.N2 (RESET#); also elsewhere on the board
DRAM_WEN: U2.H3 (WE#); also elsewhere on the board
GND: C2.2, C3.2, C4.2, C5.2, C6.2, C7.2, C8.2, C9.2, C10.2, C11.2, C12.2, C13.2, C14.2, C15.2, C16.2, C17.2, C18.2, R13.2, R14.2, R15.2, R16.2, U2.A1 (VSS), U2.A8 (VSS), U2.B1 (VSS), U2.B2 (VSSQ), U2.B8 (VSSQ), U2.C9 (VSSQ), U2.D1 (VSSQ), U2.D8 (VSS), U2.D9 (VSSQ), U2.F2 (VSS), U2.F8 (VSS), U2.J1 (VSS), U2.J9 (VSS), U2.L1 (VSS), U2.L9 (VSS), U2.N1 (VSS), U2.N9 (VSS), U3.4 (GND), U4.13 (VSS), U4.36 (VSS); also elsewhere on the board
NAND_ALE: U4.17 (ALE); also elsewhere on the board
NAND_CEN: U4.9 (CEN); also elsewhere on the board
NAND_CLE: U4.16 (CLE); also elsewhere on the board
NAND_IO0: U4.29 (IO0); also elsewhere on the board
NAND_IO1: U4.30 (IO1); also elsewhere on the board
NAND_IO2: U4.31 (IO2); also elsewhere on the board
NAND_IO3: U4.32 (IO3); also elsewhere on the board
NAND_IO4: U4.41 (IO4); also elsewhere on the board
NAND_IO5: U4.42 (IO5); also elsewhere on the board
NAND_IO6: U4.43 (IO6); also elsewhere on the board
NAND_IO7: U4.44 (IO7); also elsewhere on the board
NAND_REN: U4.8 (REN); also elsewhere on the board
NAND_R/BN: U4.7 (R/BN); also elsewhere on the board
NAND_WEN: U4.18 (WEN); also elsewhere on the board
NAND_WPN: U4.19 (WPN); also elsewhere on the board
unnamed: R13.1, U2.H8 (ZQ)
unnamed: R12.1, U3.6 (CLK)
QSPI_CLK: R12.2; also elsewhere on the board
QSPI_CSN: R9.2, U3.1 (~CS); also elsewhere on the board
QSPI_D0: U3.5 (DI(IO0)); also elsewhere on the board
QSPI_D1: U3.2 (DO(IO1)); also elsewhere on the board
QSPI_D2: R10.2, U3.3 (IO2); also elsewhere on the board
QSPI_D3: R11.2, U3.7 (IO3); also elsewhere on the board
VREF_DRAM: C17.1, C18.1, U2.E1 (VREFDQ), U2.J8 (VREFCA); also elsewhere on the board

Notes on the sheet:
QSPI Flash
DDR3L
NAND Flash

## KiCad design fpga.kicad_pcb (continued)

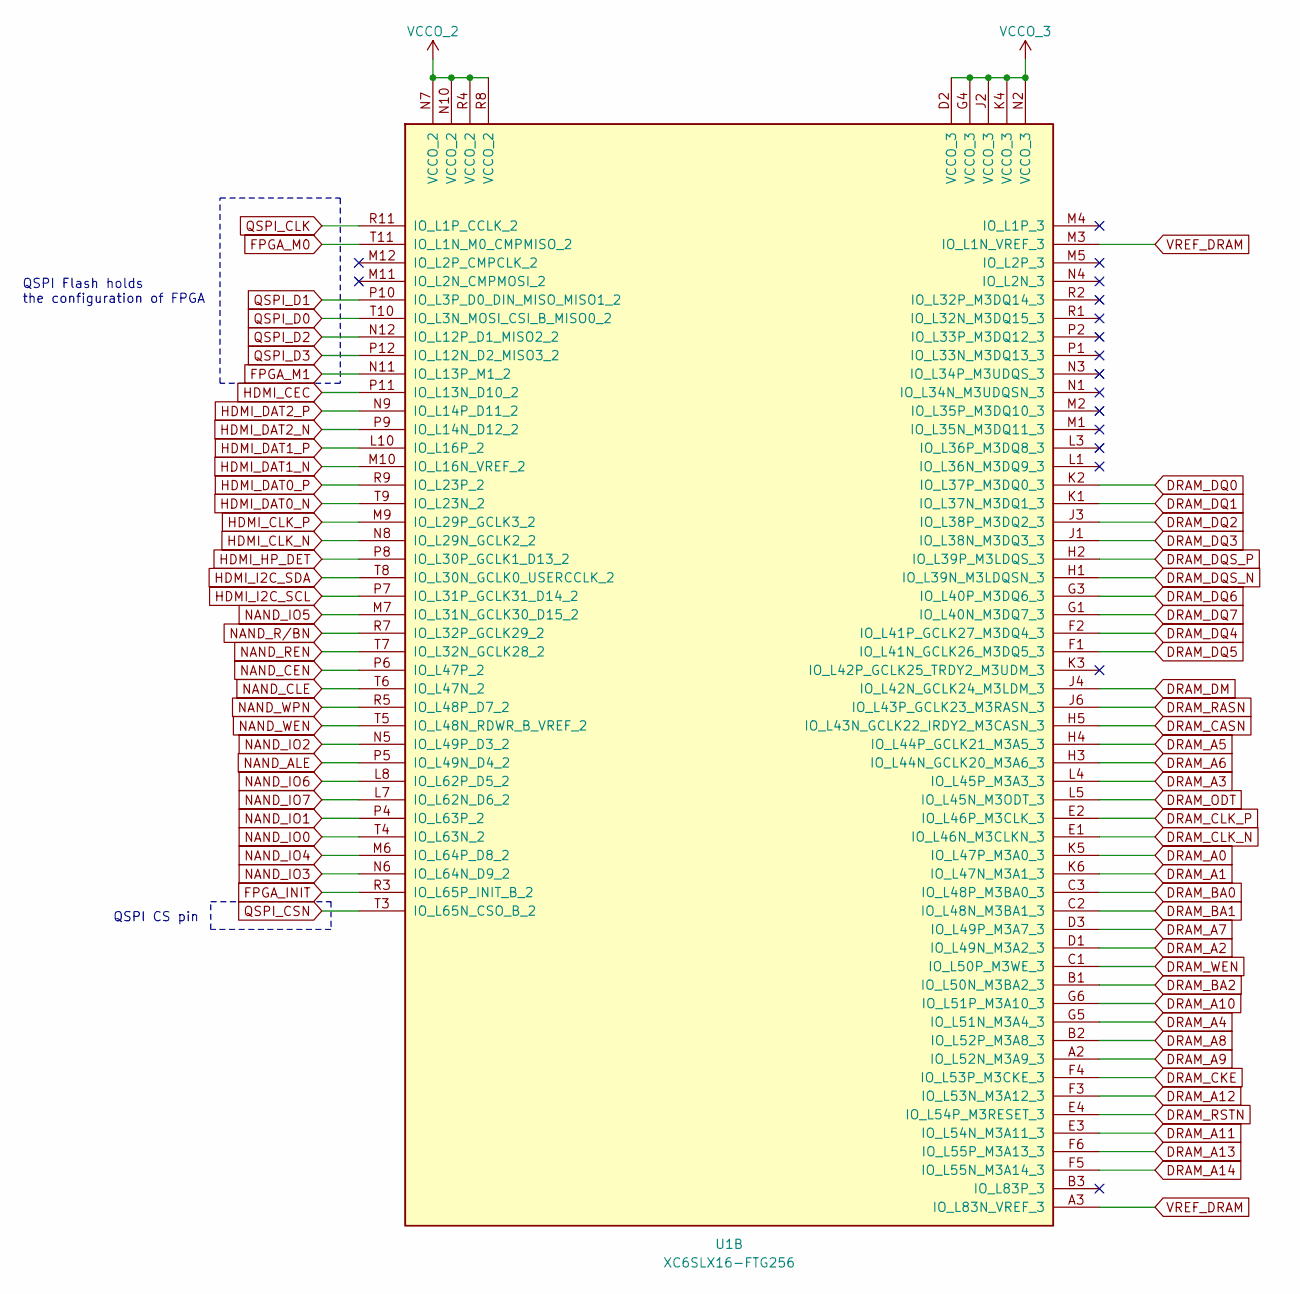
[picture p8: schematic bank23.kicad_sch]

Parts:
U1: XC6SLX16-FTG256; BGA-256_17.0x17.0mm_Layout16x16_P1.0mm_Ball0.5mm_Pad0.4mm_N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

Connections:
+1V35: U1.D2 (VCCO_3), U1.G4 (VCCO_3), U1.J2 (VCCO_3), U1.K4 (VCCO_3), U1.N2 (VCCO_3); also elsewhere on the board
+3V3: U1.N7 (VCCO_2), U1.N10 (VCCO_2), U1.R4 (VCCO_2), U1.R8 (VCCO_2); also elsewhere on the board
DRAM_A0: U1.K5 (IO_L47P_M3A0_3); also elsewhere on the board
DRAM_A1: U1.K6 (IO_L47N_M3A1_3); also elsewhere on the board
DRAM_A2: U1.D1 (IO_L49N_M3A2_3); also elsewhere on the board
DRAM_A3: U1.L4 (IO_L45P_M3A3_3); also elsewhere on the board
DRAM_A4: U1.G5 (IO_L51N_M3A4_3); also elsewhere on the board
DRAM_A5: U1.H4 (IO_L44P_GCLK21_M3A5_3); also elsewhere on the board
DRAM_A6: U1.H3 (IO_L44N_GCLK20_M3A6_3); also elsewhere on the board
DRAM_A7: U1.D3 (IO_L49P_M3A7_3); also elsewhere on the board
DRAM_A8: U1.B2 (IO_L52P_M3A8_3); also elsewhere on the board
DRAM_A9: U1.A2 (IO_L52N_M3A9_3); also elsewhere on the board
DRAM_A10: U1.G6 (IO_L51P_M3A10_3); also elsewhere on the board
DRAM_A11: U1.E3 (IO_L54N_M3A11_3); also elsewhere on the board
DRAM_A12: U1.F3 (IO_L53N_M3A12_3); also elsewhere on the board
DRAM_A13: U1.F6 (IO_L55P_M3A13_3); also elsewhere on the board
DRAM_A14: U1.F5 (IO_L55N_M3A14_3); also elsewhere on the board
DRAM_BA0: U1.C3 (IO_L48P_M3BA0_3); also elsewhere on the board
DRAM_BA1: U1.C2 (IO_L48N_M3BA1_3); also elsewhere on the board
DRAM_BA2: U1.B1 (IO_L50N_M3BA2_3); also elsewhere on the board
DRAM_CASN: U1.H5 (IO_L43N_GCLK22_IRDY2_M3CASN_3); also elsewhere on the board
DRAM_CKE: U1.F4 (IO_L53P_M3CKE_3); also elsewhere on the board
DRAM_CLK_N: U1.E1 (IO_L46N_M3CLKN_3); also elsewhere on the board
DRAM_CLK_P: U1.E2 (IO_L46P_M3CLK_3); also elsewhere on the board
DRAM_DM: U1.J4 (IO_L42N_GCLK24_M3LDM_3); also elsewhere on the board
DRAM_DQ0: U1.K2 (IO_L37P_M3DQ0_3); also elsewhere on the board
DRAM_DQ1: U1.K1 (IO_L37N_M3DQ1_3); also elsewhere on the board
DRAM_DQ2: U1.J3 (IO_L38P_M3DQ2_3); also elsewhere on the board
DRAM_DQ3: U1.J1 (IO_L38N_M3DQ3_3); also elsewhere on the board
DRAM_DQ4: U1.F2 (IO_L41P_GCLK27_M3DQ4_3); also elsewhere on the board
DRAM_DQ5: U1.F1 (IO_L41N_GCLK26_M3DQ5_3); also elsewhere on the board
DRAM_DQ6: U1.G3 (IO_L40P_M3DQ6_3); also elsewhere on the board
DRAM_DQ7: U1.G1 (IO_L40N_M3DQ7_3); also elsewhere on the board
DRAM_DQS_N: U1.H1 (IO_L39N_M3LDQSN_3); also elsewhere on the board
DRAM_DQS_P: U1.H2 (IO_L39P_M3LDQS_3); also elsewhere on the board
DRAM_ODT: U1.L5 (IO_L45N_M3ODT_3); also elsewhere on the board
DRAM_RASN: U1.J6 (IO_L43P_GCLK23_M3RASN_3); also elsewhere on the board
DRAM_RSTN: U1.E4 (IO_L54P_M3RESET_3); also elsewhere on the board
DRAM_WEN: U1.C1 (IO_L50P_M3WE_3); also elsewhere on the board
FPGA_INIT: U1.R3 (IO_L65P_INIT_B_2); also elsewhere on the board
FPGA_M0: U1.T11 (IO_L1N_M0_CMPMISO_2); also elsewhere on the board
FPGA_M1: U1.N11 (IO_L13P_M1_2); also elsewhere on the board
HDMI_CEC: U1.P11 (IO_L13N_D10_2); also elsewhere on the board
HDMI_CLK_N: U1.N8 (IO_L29N_GCLK2_2); also elsewhere on the board
HDMI_CLK_P: U1.M9 (IO_L29P_GCLK3_2); also elsewhere on the board
HDMI_DAT0_N: U1.T9 (IO_L23N_2); also elsewhere on the board
HDMI_DAT0_P: U1.R9 (IO_L23P_2); also elsewhere on the board
HDMI_DAT1_N: U1.M10 (IO_L16N_VREF_2); also elsewhere on the board
HDMI_DAT1_P: U1.L10 (IO_L16P_2); also elsewhere on the board
HDMI_DAT2_N: U1.P9 (IO_L14N_D12_2); also elsewhere on the board
HDMI_DAT2_P: U1.N9 (IO_L14P_D11_2); also elsewhere on the board
HDMI_HP_DET: U1.P8 (IO_L30P_GCLK1_D13_2); also elsewhere on the board
HDMI_I2C_SCL: U1.P7 (IO_L31P_GCLK31_D14_2); also elsewhere on the board
HDMI_I2C_SDA: U1.T8 (IO_L30N_GCLK0_USERCCLK_2); also elsewhere on the board
NAND_ALE: U1.P5 (IO_L49N_D4_2); also elsewhere on the board
NAND_CEN: U1.P6 (IO_L47P_2); also elsewhere on the board
NAND_CLE: U1.T6 (IO_L47N_2); also elsewhere on the board
NAND_IO0: U1.T4 (IO_L63N_2); also elsewhere on the board
NAND_IO1: U1.P4 (IO_L63P_2); also elsewhere on the board
NAND_IO2: U1.N5 (IO_L49P_D3_2); also elsewhere on the board
NAND_IO3: U1.N6 (IO_L64N_D9_2); also elsewhere on the board
NAND_IO4: U1.M6 (IO_L64P_D8_2); also elsewhere on the board
NAND_IO5: U1.M7 (IO_L31N_GCLK30_D15_2); also elsewhere on the board
NAND_IO6: U1.L8 (IO_L62P_D5_2); also elsewhere on the board
NAND_IO7: U1.L7 (IO_L62N_D6_2); also elsewhere on the board
NAND_REN: U1.T7 (IO_L32N_GCLK28_2); also elsewhere on the board
NAND_R/BN: U1.R7 (IO_L32P_GCLK29_2); also elsewhere on the board
NAND_WEN: U1.T5 (IO_L48N_RDWR_B_VREF_2); also elsewhere on the board
NAND_WPN: U1.R5 (IO_L48P_D7_2); also elsewhere on the board
QSPI_CLK: U1.R11 (IO_L1P_CCLK_2); also elsewhere on the board
QSPI_CSN: U1.T3 (IO_L65N_CSO_B_2); also elsewhere on the board
QSPI_D0: U1.T10 (IO_L3N_MOSI_CSI_B_MISO0_2); also elsewhere on the board
QSPI_D1: U1.P10 (IO_L3P_D0_DIN_MISO_MISO1_2); also elsewhere on the board
QSPI_D2: U1.N12 (IO_L12P_D1_MISO2_2); also elsewhere on the board
QSPI_D3: U1.P12 (IO_L12N_D2_MISO3_2); also elsewhere on the board
VREF_DRAM: U1.A3 (IO_L83N_VREF_3), U1.M3 (IO_L1N_VREF_3); also elsewhere on the board

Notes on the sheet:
QSPI Flash holds the configuration of FPGA
QSPI CS pin

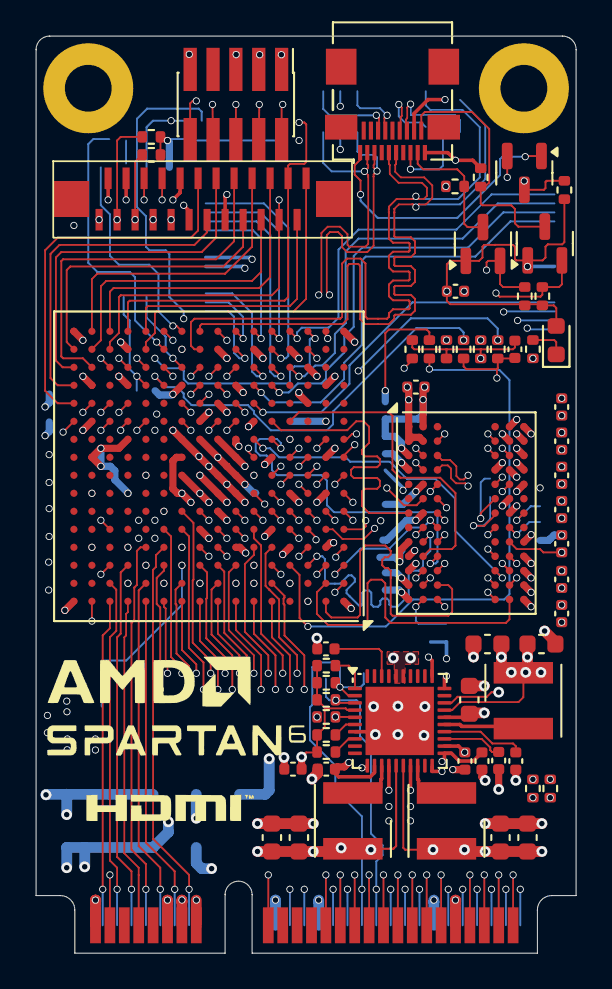
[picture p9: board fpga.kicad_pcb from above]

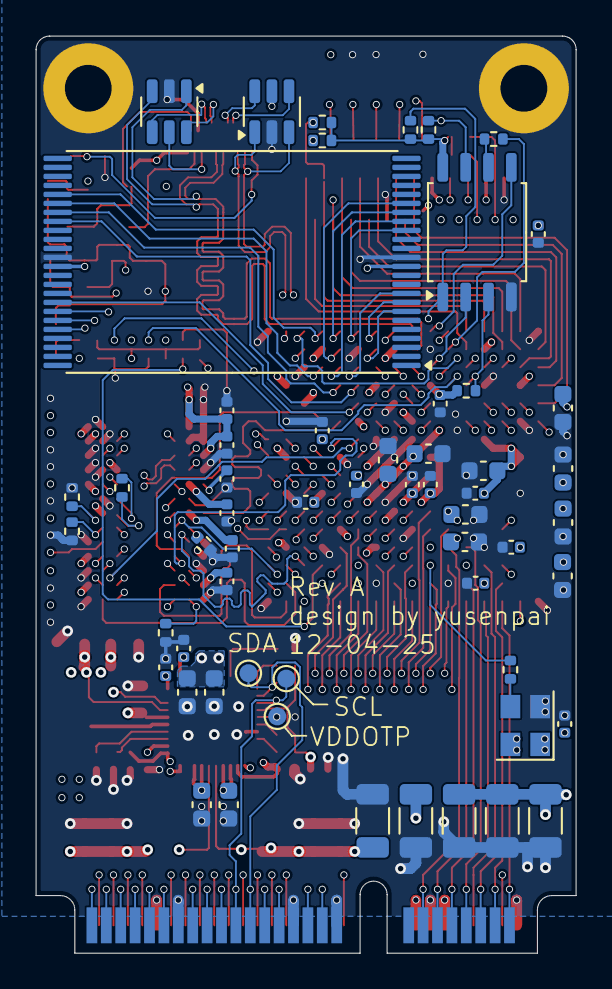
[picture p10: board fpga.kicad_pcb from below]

Board: 8 copper layers, 30.0 x 51.0 mm, 117 parts (57 on the bottom side), 167 nets.
